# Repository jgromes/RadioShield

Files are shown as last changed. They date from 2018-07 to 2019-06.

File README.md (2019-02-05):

# Arduino Radio Shield

## "The Swiss Army Knife of Arduino Radio shields" - [Hackaday.com blog](https://hackaday.com/2018/07/28/why-have-only-one-radio-when-you-can-have-two/)

### Designed for use with [RadioLib](https://github.com/jgromes/RadioLib) - Universal wireless communication library for Arduino.

## Revision C
The latest hardware revision, compatible with both 5V and 3.3V Arduino boards. The entire project was also rebranded as Radio Shield!

Additional modules:
* **SIM800C** GSM module
* **CC1101** FSK module
* **nRF24L01** 2.4 GHz module

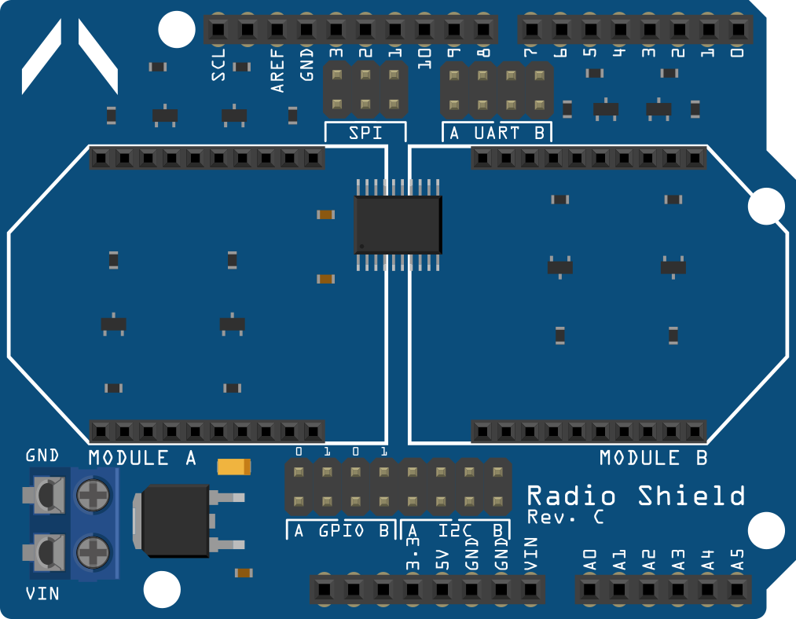
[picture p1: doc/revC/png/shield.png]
Radio Shield Rev.C


## Revision B
Added some improvements over rev. A, such as improved Arduino Mega support and interrupt selection pin header.

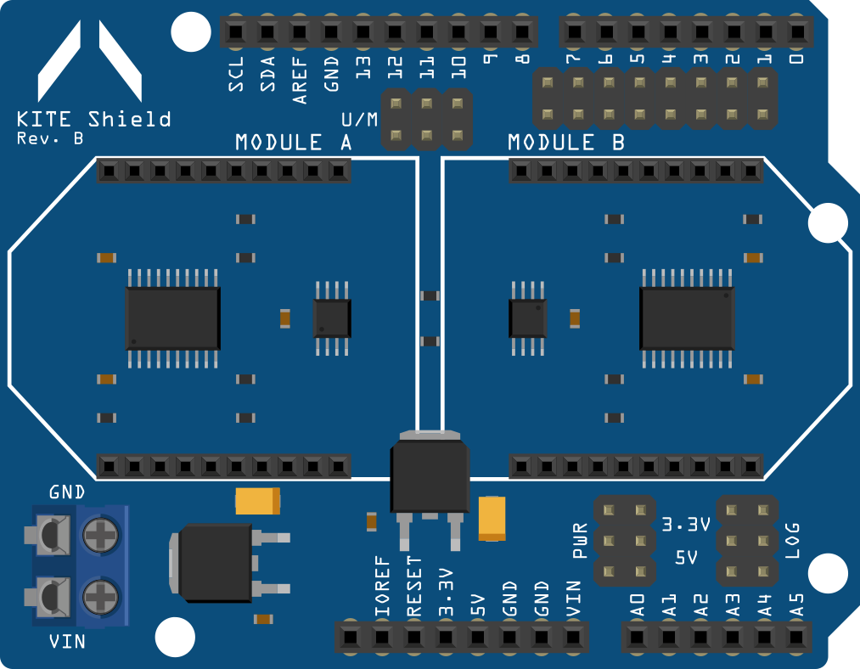
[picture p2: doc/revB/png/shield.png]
KITE Shield Rev.B


## Revision A
After a first few prototypes, rev. A is the first fully tested and working shield.  
Supported modules:
* **ESP8266** WiFi module
* **HC-05** Bluetooth module
* **RFM69** FSK/OOK radio module
* **SX127x** series LoRa modules - including SX1272, SX1276 and SX1278
* **XBee** modules (S2B)

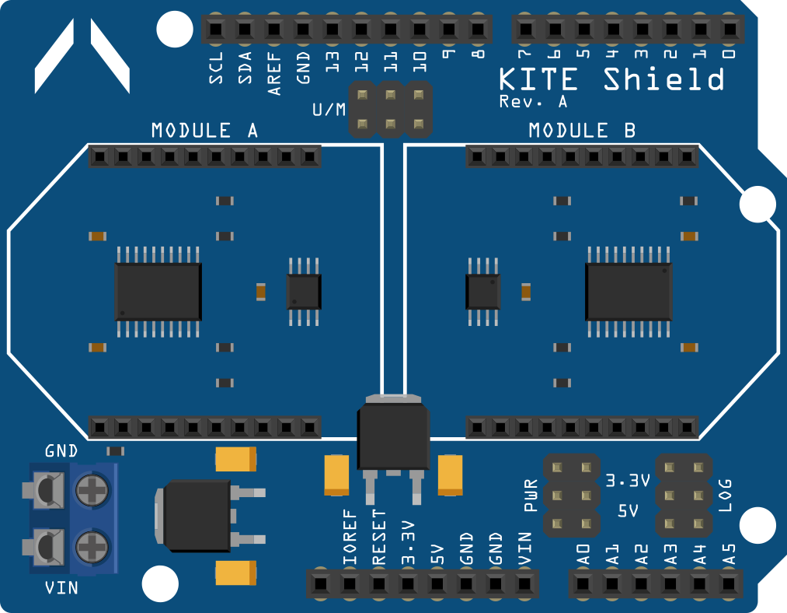
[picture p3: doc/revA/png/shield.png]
KITE Shield Rev.A


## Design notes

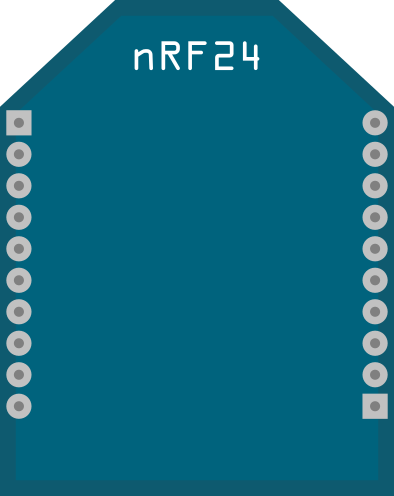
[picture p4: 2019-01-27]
doc/revC/png/module_nRF24.png

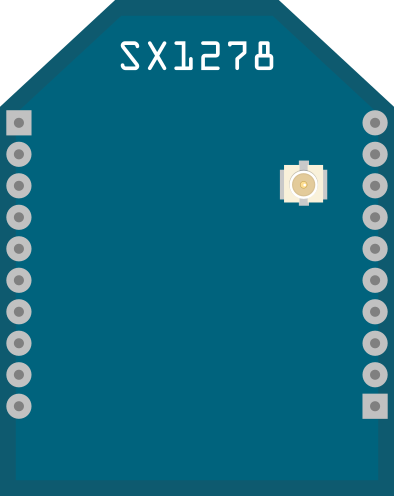
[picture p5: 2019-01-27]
doc/revC/png/module_SX1278_type1.png

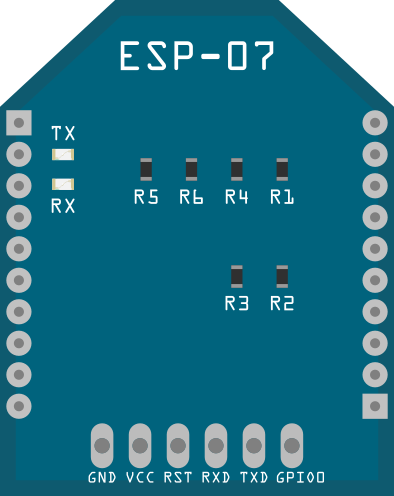
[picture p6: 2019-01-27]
doc/revC/png/module_ESP07.png

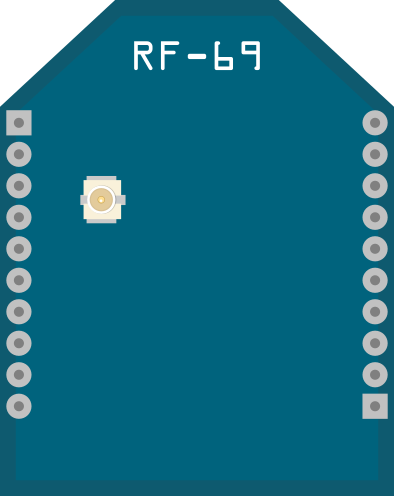
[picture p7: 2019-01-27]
doc/revC/png/module_RF69.png

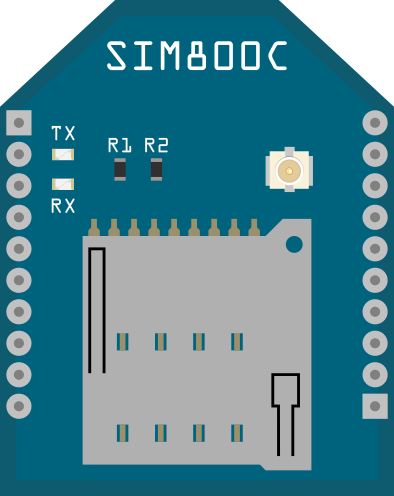
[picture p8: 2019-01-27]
doc/revC/png/module_SIM800C.png

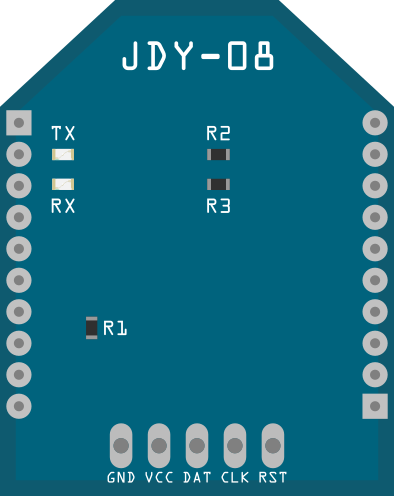
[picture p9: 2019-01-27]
doc/revC/png/module_JDY08.png

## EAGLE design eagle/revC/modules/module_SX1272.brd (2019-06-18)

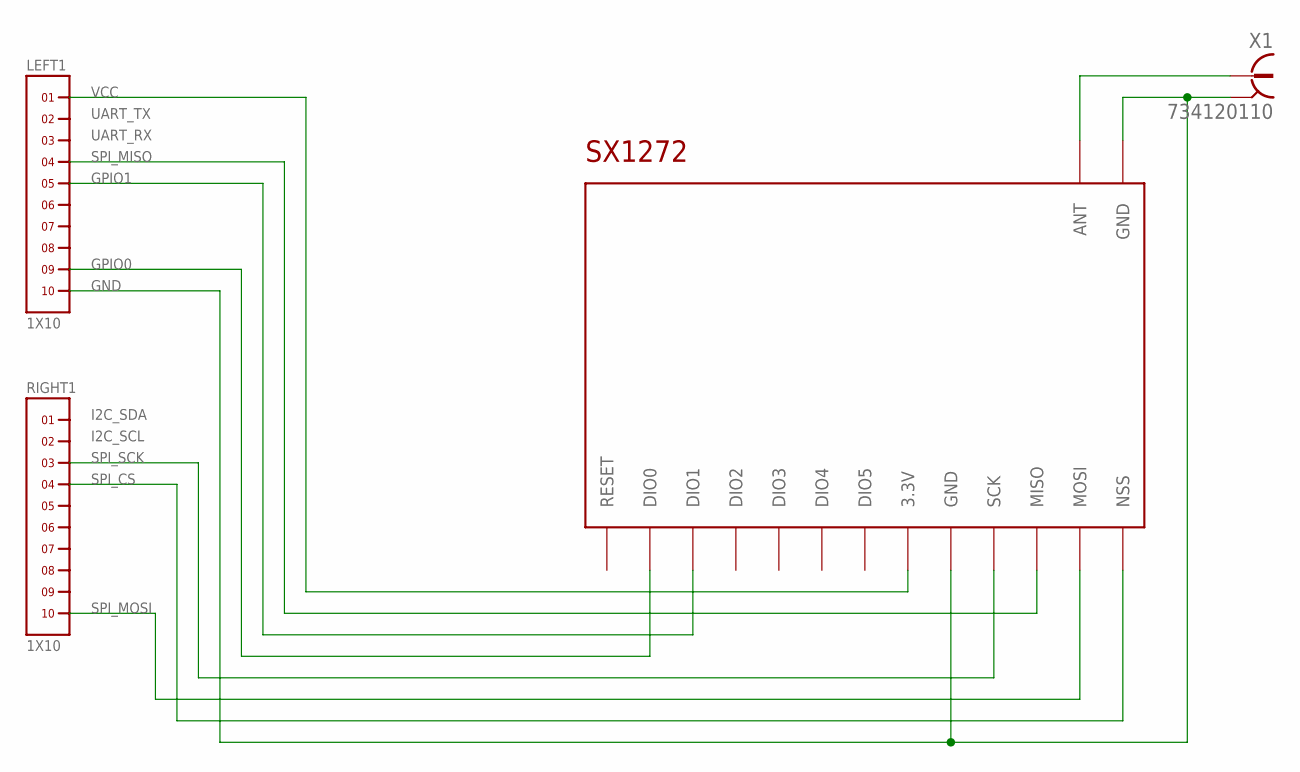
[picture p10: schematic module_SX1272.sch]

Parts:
LEFT1: 1X10
RIGHT1: 1X10
U$1: SX1272
X1: 734120110

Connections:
GND: LEFT1.10, U$1.GND@1 (GND), U$1.GND@2 (GND), X1.S@1 (2), X1.S@2 (2), X1.S@3 (2)
unnamed: U$1.ANT, X1.1
unnamed: LEFT1.9, U$1.DIO0
unnamed: RIGHT1.10, U$1.MOSI
unnamed: RIGHT1.4, U$1.NSS
unnamed: RIGHT1.3, U$1.SCK
unnamed: LEFT1.5, U$1.DIO1
unnamed: LEFT1.4, U$1.MISO
VCC: LEFT1.1, U$1.3.3V

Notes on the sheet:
VCC
UART_TX
UART_RX
SPI_MISO
GPIO1
GND
GPIO0
SPI_MOSI
I2C_SDA
I2C_SCL
SPI_SCK
SPI_CS

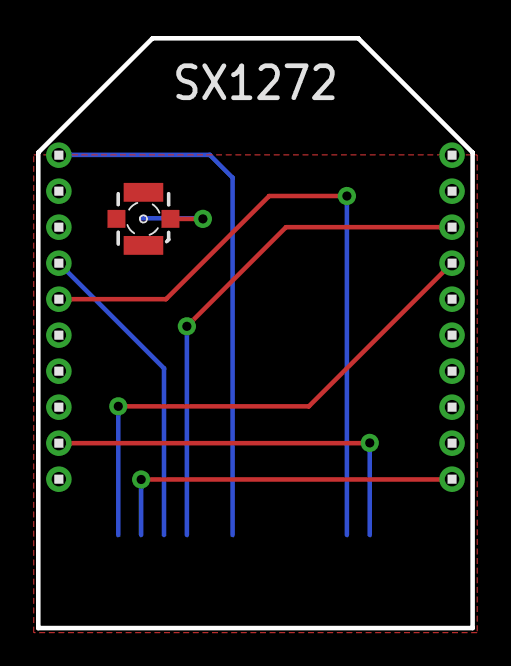
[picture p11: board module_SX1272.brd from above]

Board: 2 copper layers, 24.1 x 32.8 mm, 4 parts (1 on the bottom side), 9 nets.

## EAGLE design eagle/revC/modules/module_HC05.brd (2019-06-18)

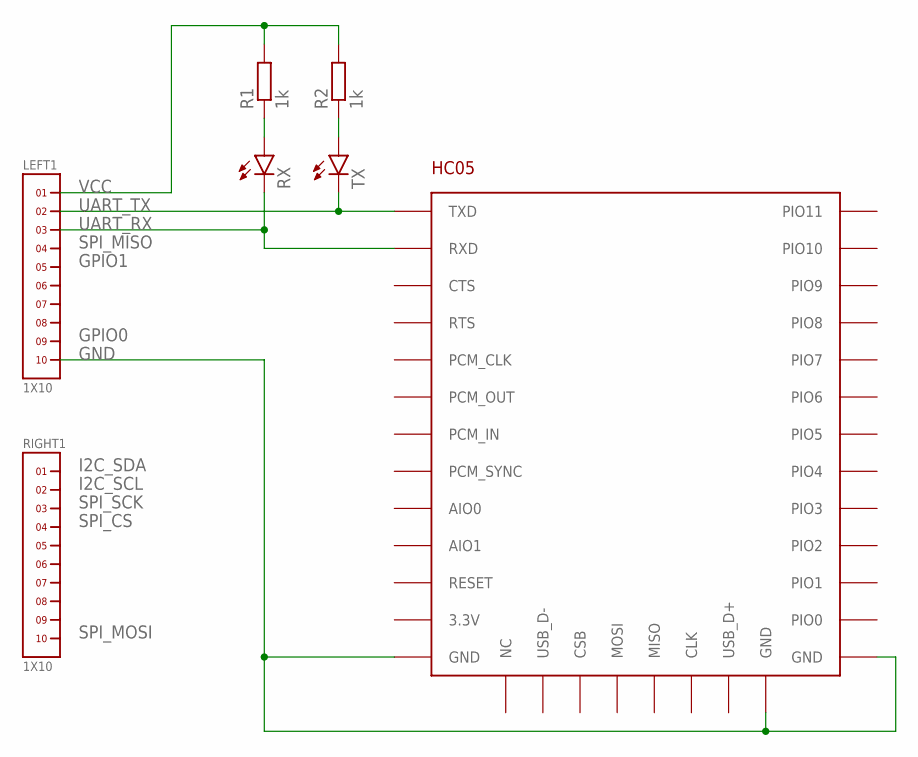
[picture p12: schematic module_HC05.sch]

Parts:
LEFT1: 1X10
R1, R2: 1k; R0603
RIGHT1: 1X10
RX: LEDCHIP-LED0603; CHIP-LED0603
TX: LEDCHIP-LED0603; CHIP-LED0603
U$1: HC05

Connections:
GND: LEFT1.10, U$1.GND@1 (GND), U$1.GND@2 (GND), U$1.GND@3 (GND)
unnamed: R2.1, TX.A
unnamed: R1.1, RX.A
unnamed: LEFT1.2, TX.C, U$1.TX (TXD)
unnamed: LEFT1.3, RX.C, U$1.RX (RXD)
VCC: LEFT1.1, R1.2, R2.2

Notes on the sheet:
VCC
I2C_SDA
I2C_SCL
SPI_SCK
SPI_CS
SPI_MOSI
UART_TX
UART_RX
SPI_MISO
GPIO1
GPIO0
GND

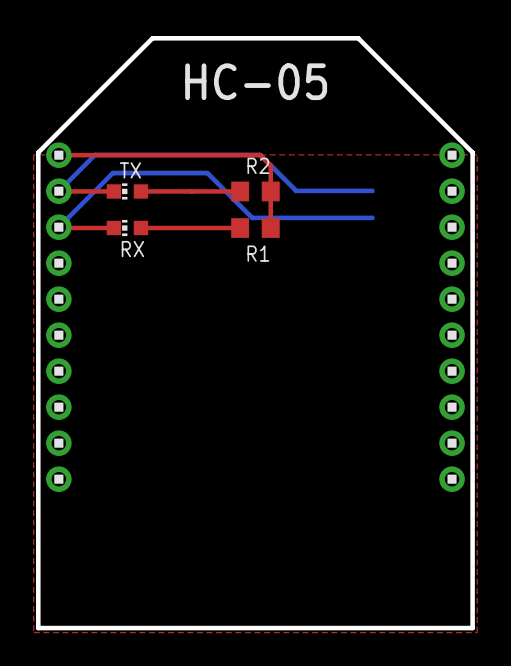
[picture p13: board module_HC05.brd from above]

Board: 2 copper layers, 24.1 x 32.8 mm, 7 parts (1 on the bottom side), 6 nets.

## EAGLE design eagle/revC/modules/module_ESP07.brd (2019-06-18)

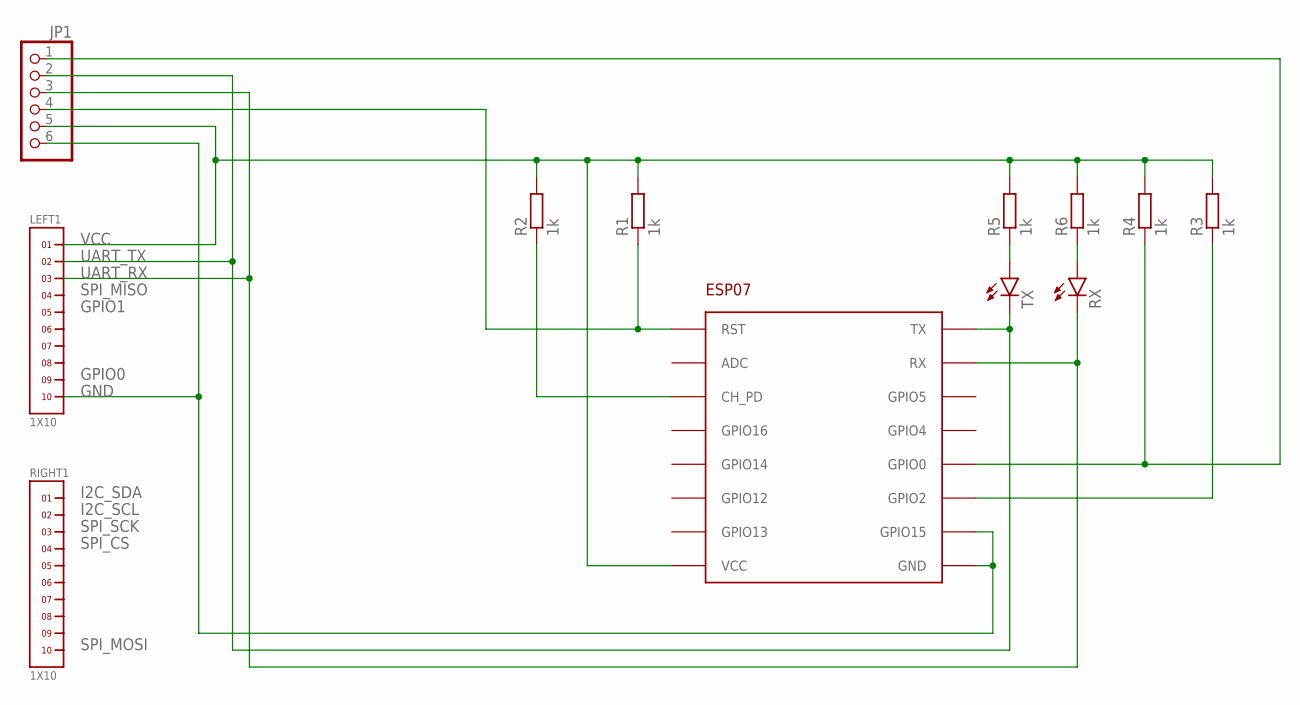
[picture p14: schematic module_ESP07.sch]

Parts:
JP1: PINHD-1X6; 1X06
LEFT1: 1X10
R1, R2, R3, R4, R5, R6: 1k; R0603
RIGHT1: 1X10
RX: LEDCHIPLED_0603; CHIPLED_0603
TX: LEDCHIPLED_0603; CHIPLED_0603
U$1: ESP-07; ESP07

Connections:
GND: JP1.6, LEFT1.10, U$1.GND, U$1.GPIO15
GPIO0: JP1.1, R4.1, U$1.GPIO0
unnamed: R6.1, RX.A
unnamed: R5.1, TX.A
unnamed: R2.1, U$1.CH_PD
unnamed: R3.1, U$1.GPIO2
RST: JP1.4, R1.1, U$1.RST
UART_RX: JP1.3, LEFT1.3, RX.C, U$1.RX
UART_TX: JP1.2, LEFT1.2, TX.C, U$1.TX
VCC: JP1.5, LEFT1.1, R1.2, R2.2, R3.2, R4.2, R5.2, R6.2, U$1.VCC

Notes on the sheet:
VCC
I2C_SDA
I2C_SCL
SPI_SCK
SPI_CS
SPI_MOSI
UART_TX
UART_RX
SPI_MISO
GPIO1
GPIO0
GND

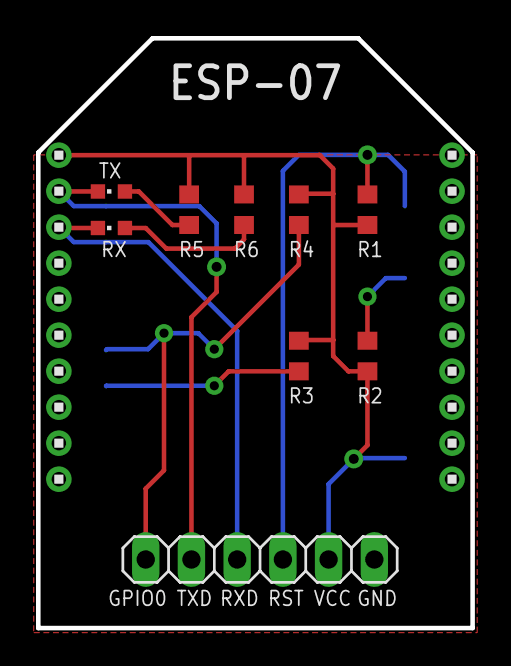
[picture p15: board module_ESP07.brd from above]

Board: 2 copper layers, 24.1 x 32.8 mm, 12 parts (1 on the bottom side), 10 nets.

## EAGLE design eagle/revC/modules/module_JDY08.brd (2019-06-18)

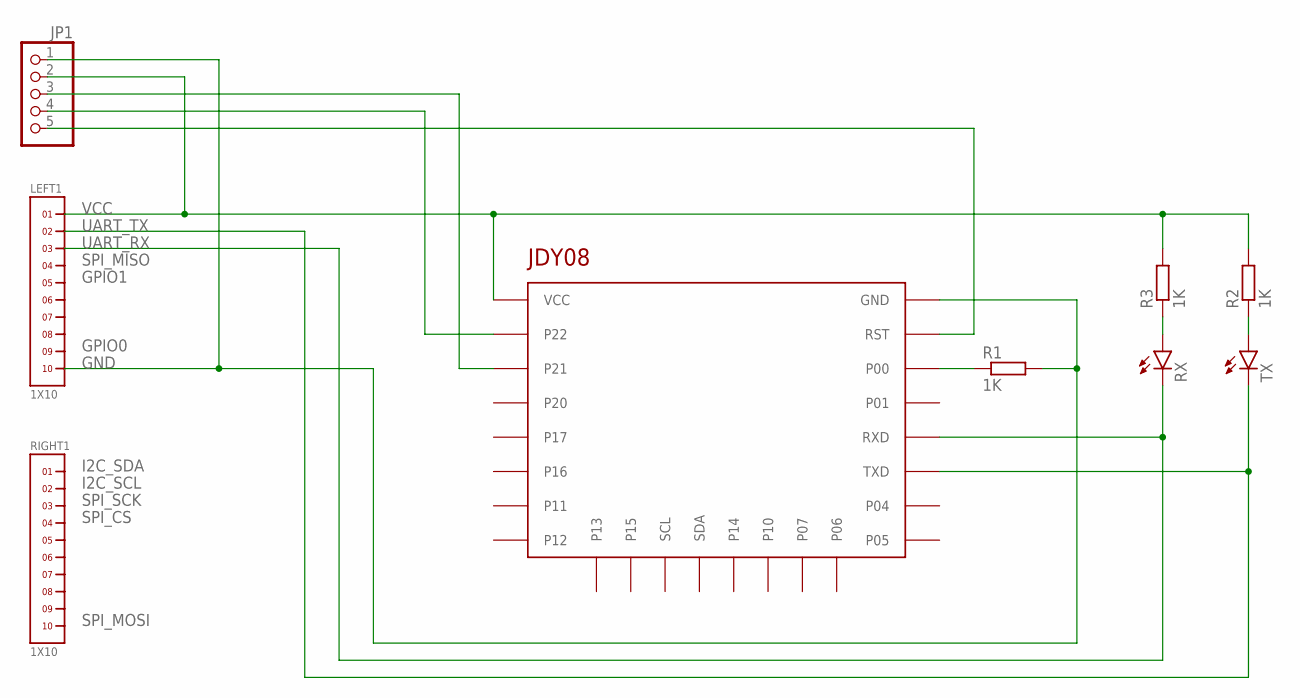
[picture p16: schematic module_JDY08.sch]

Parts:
JP1: PINHD-1X5; 1X05
LEFT1: 1X10
R1, R2, R3: 1K; R0603
RIGHT1: 1X10
RX: LEDCHIPLED_0603; CHIPLED_0603
TX: LEDCHIPLED_0603; CHIPLED_0603
U$1: JDY08

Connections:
GND: JP1.1, LEFT1.10, R1.2, U$1.GND
unnamed: JP1.5, U$1.RST
unnamed: JP1.3, U$1.P21
unnamed: JP1.4, U$1.P22
unnamed: LEFT1.3, RX.C, U$1.RXD
unnamed: R2.1, TX.A
unnamed: R3.1, RX.A
unnamed: R1.1, U$1.P00
unnamed: LEFT1.2, TX.C, U$1.TXD
VCC: JP1.2, LEFT1.1, R2.2, R3.2, U$1.VCC

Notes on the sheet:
VCC
I2C_SDA
I2C_SCL
SPI_SCK
SPI_CS
SPI_MOSI
UART_TX
UART_RX
SPI_MISO
GPIO1
GPIO0
GND

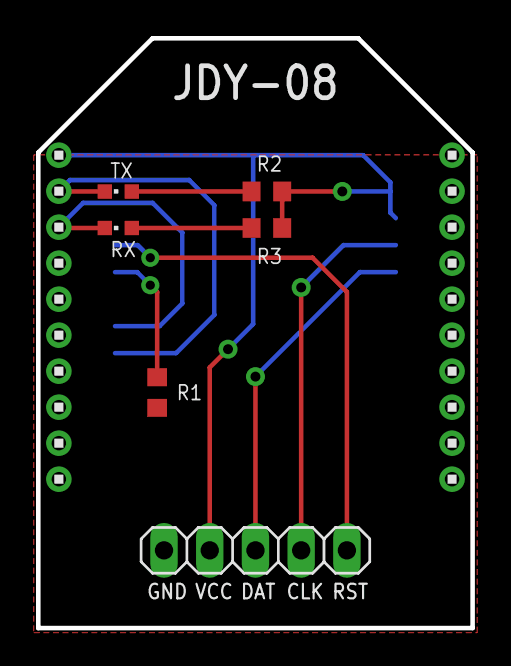
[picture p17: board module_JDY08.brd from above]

Board: 2 copper layers, 24.1 x 32.8 mm, 9 parts (1 on the bottom side), 10 nets.

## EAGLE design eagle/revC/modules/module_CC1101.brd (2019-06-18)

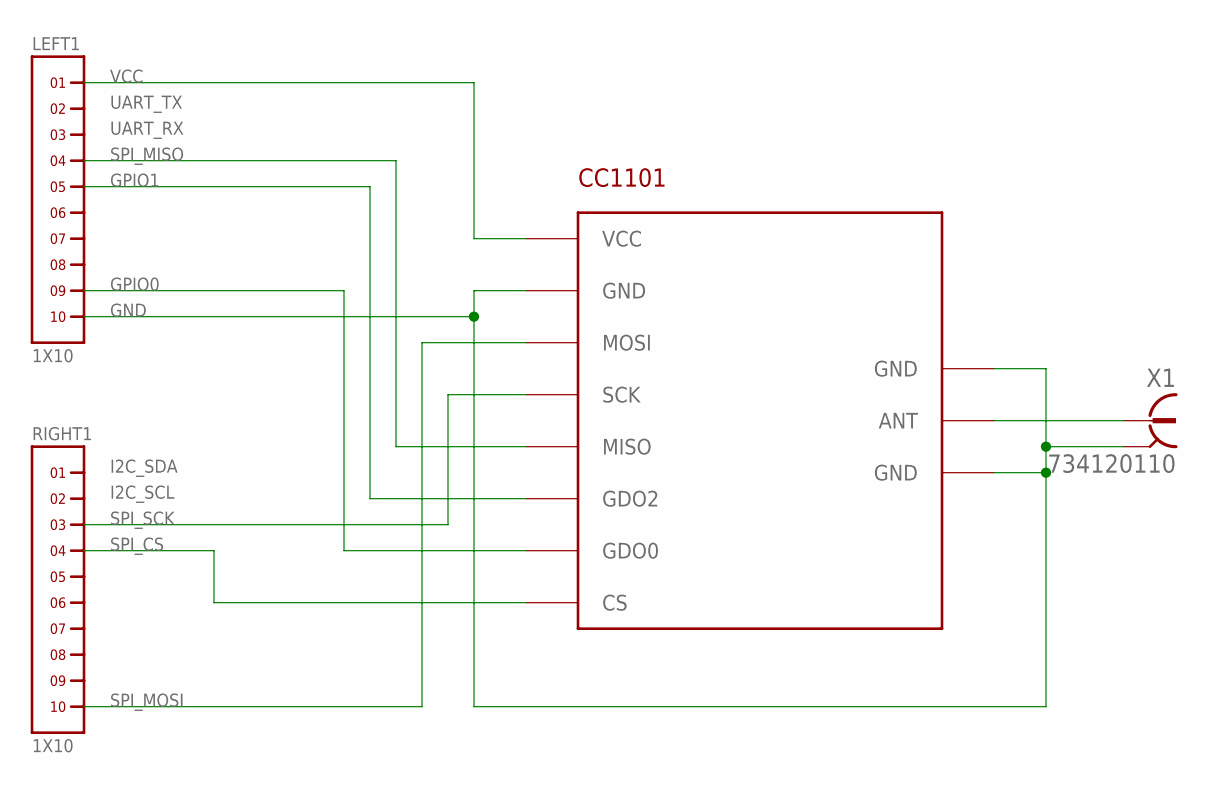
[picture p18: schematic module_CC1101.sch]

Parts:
CC1101: CC1101
LEFT1: 1X10
RIGHT1: 1X10
X1: 734120110

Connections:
GND: CC1101.GND@1 (GND), CC1101.GND@2 (GND), CC1101.GND@3 (GND), LEFT1.10, X1.S@1 (2), X1.S@2 (2), X1.S@3 (2)
INT0: CC1101.GDO0, LEFT1.9
INT1: CC1101.GDO2, LEFT1.5
unnamed: CC1101.ANT, X1.1
SPI_CS: CC1101.CS, RIGHT1.4
SPI_MISO: CC1101.MISO, LEFT1.4
SPI_MOSI: CC1101.MOSI, RIGHT1.10
SPI_SCK: CC1101.SCK, RIGHT1.3
VCC: CC1101.VCC, LEFT1.1

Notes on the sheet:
VCC
UART_TX
UART_RX
SPI_MISO
GPIO1
GND
GPIO0
SPI_MOSI
I2C_SDA
I2C_SCL
SPI_SCK
SPI_CS

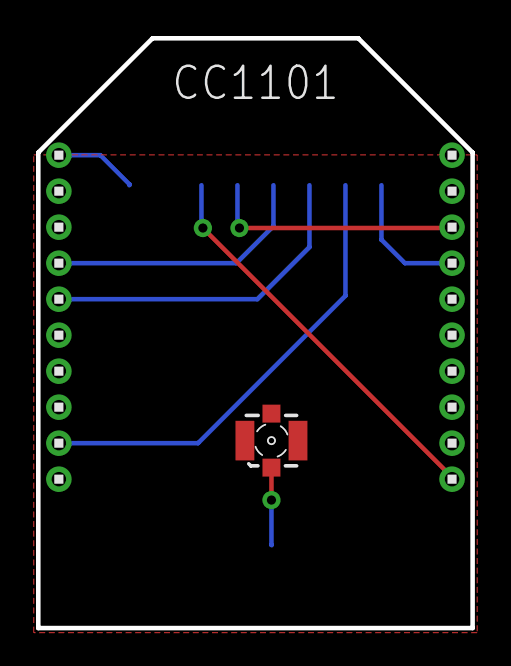
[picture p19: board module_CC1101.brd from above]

Board: 2 copper layers, 24.1 x 32.8 mm, 4 parts (1 on the bottom side), 9 nets.

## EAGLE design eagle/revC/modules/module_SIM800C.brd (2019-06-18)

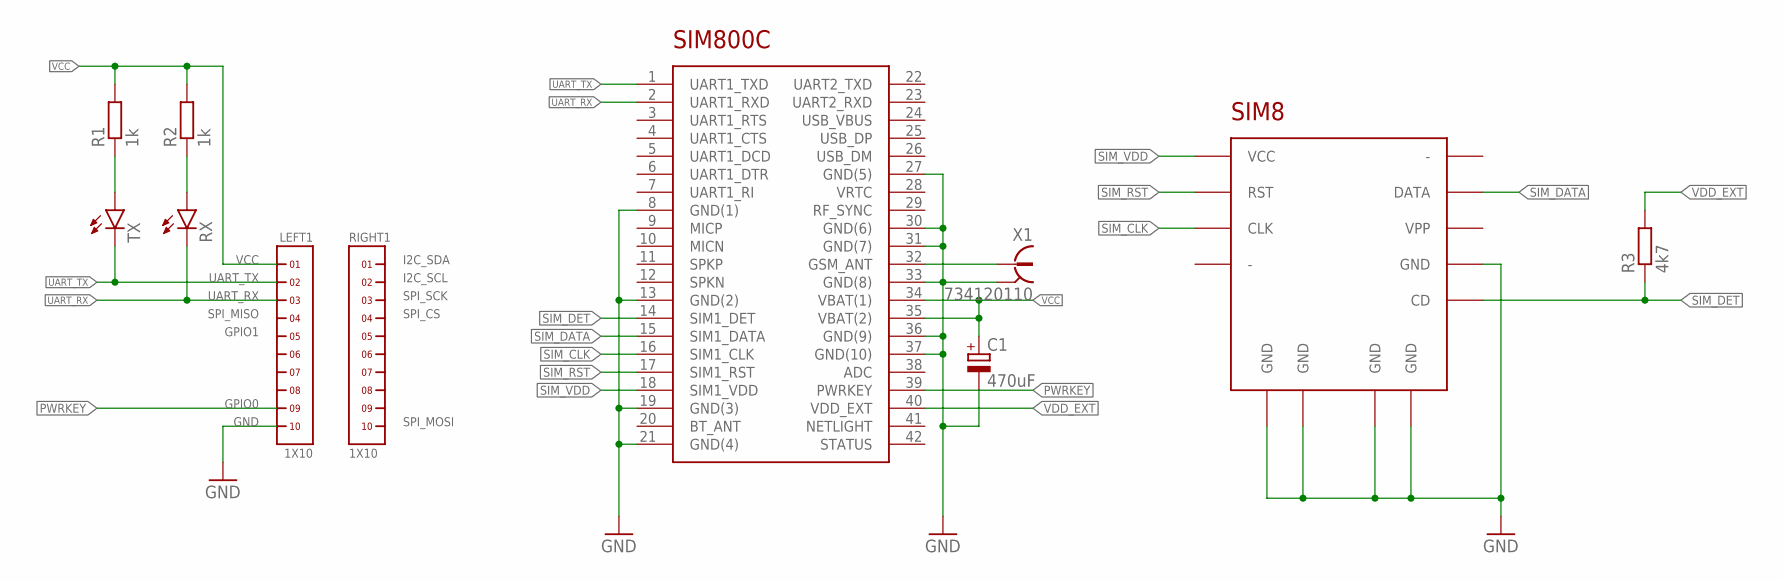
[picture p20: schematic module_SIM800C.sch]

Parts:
C1: 470uF; SMC_D
IC1: SIM800C
LEFT1: 1X10
R1, R2: 1k; R0603
R3: 4k7; R0603
RIGHT1: 1X10
RX: LEDCHIPLED_0603; CHIPLED_0603
TX: LEDCHIPLED_0603; CHIPLED_0603
U$2: 115Q-BCA0
X1: 734120110

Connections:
GND: C1.-, IC1.8 (GND(1)), IC1.13 (GND(2)), IC1.19 (GND(3)), IC1.21 (GND(4)), IC1.27 (GND(5)), IC1.30 (GND(6)), IC1.31 (GND(7)), IC1.33 (GND(8)), IC1.36 (GND(9)), IC1.37 (GND(10)), LEFT1.10, U$2.P$5 (GND), U$2.P$10 (GND), U$2.P$11 (GND), U$2.P$12 (GND), U$2.P$13 (GND), X1.S@1 (2), X1.S@2 (2), X1.S@3 (2)
unnamed: IC1.32 (GSM_ANT), X1.1
unnamed: R1.1, TX.A
unnamed: R2.1, RX.A
PWRKEY: IC1.39 (PWRKEY), LEFT1.9
SIM_CLK: IC1.16 (SIM1_CLK), U$2.P$3 (CLK)
SIM_DATA: IC1.15 (SIM1_DATA), U$2.P$7 (DATA)
SIM_DET: IC1.14 (SIM1_DET), R3.1, U$2.P$9 (CD)
SIM_RST: IC1.17 (SIM1_RST), U$2.P$2 (RST)
SIM_VDD: IC1.18 (SIM1_VDD), U$2.P$1 (VCC)
UART_RX: IC1.2 (UART1_RXD), LEFT1.3, RX.C
UART_TX: IC1.1 (UART1_TXD), LEFT1.2, TX.C
VCC: C1.+, IC1.34 (VBAT(1)), IC1.35 (VBAT(2)), LEFT1.1, R1.2, R2.2
VDD_EXT: IC1.40 (VDD_EXT), R3.2

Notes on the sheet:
VCC
UART_TX
UART_RX
SPI_MISO
GPIO1
GND
GPIO0
SPI_MOSI
I2C_SDA
I2C_SCL
SPI_SCK
SPI_CS

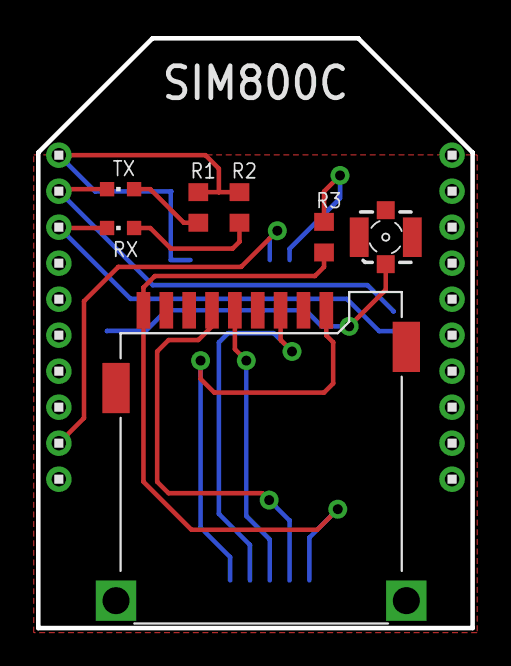
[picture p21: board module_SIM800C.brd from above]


Board: 2 copper layers, 24.1 x 32.8 mm, 11 parts (2 on the bottom side), 14 nets.

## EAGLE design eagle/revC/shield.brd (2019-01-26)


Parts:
AD: PINHD-1X6; 1X06
C1, C3, C4: 0.1 uF; C0603
C2: 2.2 uF; SMC_A
CON_A_LEFT: 1X10
CON_A_RIGHT: 1X10
CON_B_LEFT: 1X10
CON_B_RIGHT: 1X10
GPIO: PINHD-2X4; 2X04
I2C: PINHD-2X4; 2X04
IOH: PINHD-1X10; 1X10
IOL: PINHD-1X8; 1X08
POWER: PINHD-1X8; 1X08
POWER_IN: W237-102
Q1, Q2, Q3, Q4, Q5, Q6, Q7, Q8: BSS138; SOT23
R1, R2, R3, R4, R5, R6, R7, R8, R9, R10, R11, R12, R13, R14, R15, R16: 10k; R0603
SPI: PINHD-2X3; 2X03
U1: MAX3001; TSSOP20
U2: KF33BDT-TR; TO228P972X240-3N
UART: PINHD-2X4; 2X04

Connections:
+3V3: C2.+, CON_A_LEFT.1, CON_B_LEFT.1, U2.3 (OUTPUT)
+3V3_REF: C3.1, POWER.4, Q1.1 (G), Q2.1 (G), Q3.1 (G), Q4.1 (G), Q5.1 (G), Q6.1 (G), Q7.1 (G), Q8.1 (G), R1.2, R3.2, R5.2, R7.2, R9.2, R11.2, R13.2, R15.2, U1.2 (VL), U1.10 (EN)
+5V0_REF: POWER.5
ARD_CS_A: IOH.8, U1.16 (VCC4)
ARD_CS_B: IOL.3, U1.15 (VCC5)
ARD_GPIO0: IOL.6, Q2.3 (D), R4.1
ARD_GPIO1: IOL.5, Q1.3 (D), R2.1
ARD_MISO: SPI.3, U1.18 (VCC2)
ARD_MOSI: SPI.5, U1.17 (VCC3)
ARD_RX_A: Q5.3 (D), R10.1, UART.1
ARD_RX_B: Q7.3 (D), R14.1, UART.5
ARD_SCK: SPI.1, U1.20 (VCC1)
ARD_SCL: IOH.1, Q4.3 (D), R8.1
ARD_SDA: IOH.2, Q3.3 (D), R6.1
ARD_TX_A: Q6.3 (D), R12.1, UART.3
ARD_TX_B: Q8.3 (D), R16.1, UART.7
CON_A_CS: CON_A_RIGHT.4, U1.5 (VL4)
CON_A_GPIO0: CON_A_LEFT.9, GPIO.4
CON_A_GPIO1: CON_A_LEFT.5, GPIO.2
CON_A_RX: CON_A_LEFT.2, Q5.2 (S), R9.1
CON_A_SCL: CON_A_RIGHT.2, I2C.4
CON_A_SDA: CON_A_RIGHT.1, I2C.2
CON_A_TX: CON_A_LEFT.3, Q6.2 (S), R11.1
CON_B_CS: CON_B_RIGHT.4, U1.6 (VL5)
CON_B_GPIO0: CON_B_LEFT.9, GPIO.8
CON_B_GPIO1: CON_B_LEFT.5, GPIO.6
CON_B_RX: CON_B_LEFT.2, Q7.2 (S), R13.1
CON_B_SCL: CON_B_RIGHT.2, I2C.8
CON_B_SDA: CON_B_RIGHT.1, I2C.6
CON_B_TX: CON_B_LEFT.3, Q8.2 (S), R15.1
CON_MISO: CON_A_LEFT.4, CON_B_LEFT.4, U1.3 (VL2)
CON_MOSI: CON_A_RIGHT.10, CON_B_RIGHT.10, U1.4 (VL3)
CON_SCK: CON_A_RIGHT.3, CON_B_RIGHT.3, U1.1 (VL1)
GND: C1.2, C2.-, C3.2, C4.2, CON_A_LEFT.10, CON_B_LEFT.10, IOH.4, POWER.6, POWER.7, POWER_IN.1, U1.11 (GND), U2.4 (GND_TAB)
GPIO0_S: GPIO.3, GPIO.7, Q2.2 (S), R3.1
GPIO1_S: GPIO.1, GPIO.5, Q1.2 (S), R1.1
IOREF: C4.1, POWER.2, R2.2, R4.2, R6.2, R8.2, R10.2, R12.2, R14.2, R16.2, U1.19 (VCC)
RESET: POWER.3
SCL_S: I2C.3, I2C.7, Q4.2 (S), R7.1
SDA_S: I2C.1, I2C.5, Q3.2 (S), R5.1
UNO_MISO: IOH.6, SPI.4
UNO_MOSI: IOH.7, SPI.6
UNO_RX_A: IOH.9, UART.2
UNO_RX_B: IOL.1, UART.6
UNO_SCK: IOH.5, SPI.2
UNO_TX_A: IOH.10, UART.4
UNO_TX_B: IOL.2, UART.8
VIN: C1.1, POWER.8, POWER_IN.2, U2.1 (INPUT)

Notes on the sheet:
Jan Gromes
AREF
SDA
SCL
VIN
GND
3.3V
RESET
IOREF
MODULE B LEVEL TRANSLATORS
MODULE A LEVEL TRANSLATORS
MODULE A
MODULE B
POWER
ARDUINO HEADERS
Arduino Radio shield
Designed in Czech Republic by Atlas Inc.
CONFIGURATION HEADERS
COMMON LEVEL TRANSLATORS
Notes: 1. UART signal names respect data flow to/from Arduino.


Board: 2 copper layers, 68.6 x 53.3 mm, 43 parts (0 on the bottom side), 46 nets.

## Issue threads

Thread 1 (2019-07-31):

What's about ESP32 support ?

Vorms, 2019-07-31:
All is in the title...

Best regards

jgromes, 2019-07-31:
RadioShield is compatible with any board that's compatible with Arduino Uno R3.

Did you mean to post this in https://github.com/jgromes/RadioLib?

Vorms, 2019-07-31:
yes of corse for the library
Thanks
I am intersted about a RF69 -> MQTT !

Best regards and thanks for your works

jgromes, 2019-07-31:
Could you post this to the library repository? Thanks

Closed 2019-07-31.

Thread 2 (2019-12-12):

Library Errors Latest Version w/ Artemis RedBoard

cvoalex, 2019-12-12:
Latest version trying to compile the Transmit and Receive demos for SX126x with an Artemis Redboard.   Seems new function setpin that was not in previous versions doesnt have correct parameters when compiled for Artemis.

"C:\\Users\\Alexander\\AppData\\Local\\Arduino15\\packages\\SparkFun\\tools\\arm-none-eabi-gcc\\8-2018-q4-major/bin/arm-none-eabi-g++" -DPART_apollo3 -DAM_PACKAGE_BGA -DAM_PART_APOLLO3 -c -g -MMD -mcpu=cortex-m4 -mthumb -mfloat-abi=hard -fdata-sections -Os -ffunction-sections -std=gnu++11 -fno-threadsafe-statics -nostdlib --param max-inline-insns-single=500 -fno-rtti -fno-exceptions -DF_CPU=48000000L -DARDUINO=10810 -DARDUINO_AM_AP3_SFE_BB_ARTEMIS -DARDUINO_ARCH_APOLLO3 "-IC:\\Users\\Alexander\\AppData\\Local\\Arduino15\\packages\\SparkFun\\hardware\\apollo3\\1.0.17\\variants\\SparkFun_RedBoard_Artemis/config" "-IC:\\Users\\Alexander\\AppData\\Local\\Arduino15\\packages\\SparkFun\\hardware\\apollo3\\1.0.17\\variants\\SparkFun_RedBoard_Artemis/bsp" "-IC:\\Users\\Alexander\\AppData\\Local\\Arduino15\\packages\\SparkFun\\hardware\\apollo3\\1.0.17/cores/arduino/ard_sup" "-IC:\\Users\\Alexander\\AppData\\Local\\Arduino15\\packages\\SparkFun\\hardware\\apollo3\\1.0.17/cores/arduino/ard_sup/ard_supers" "-IC:\\Users\\Alexander\\AppData\\Local\\Arduino15\\packages\\SparkFun\\hardware\\apollo3\\1.0.17\\cores\\arduino" "-IC:\\Users\\Alexander\\AppData\\Local\\Arduino15\\packages\\SparkFun\\hardware\\apollo3\\1.0.17\\variants\\SparkFun_RedBoard_Artemis" "-IC:\\Users\\Alexander\\Documents\\Arduino\\libraries\\RadioLib\\src" "-IC:\\Users\\Alexander\\AppData\\Local\\Arduino15\\packages\\SparkFun\\hardware\\apollo3\\1.0.17\\libraries\\SPI\\src" "-IC:\\Users\\Alexander\\AppData\\Local\\Arduino15\\packages\\SparkFun\\hardware\\apollo3\\1.0.17\\libraries\\SoftwareSerial\\src" "-IC:\\Users\\Alexander\\AppData\\Local\\Arduino15\\packages\\SparkFun\\hardware\\apollo3\\1.0.17/cores/arduino/am_sdk_ap3/mcu/apollo3" "-IC:\\Users\\Alexander\\AppData\\Local\\Arduino15\\packages\\SparkFun\\hardware\\apollo3\\1.0.17/cores/arduino/am_sdk_ap3/mcu/apollo3/hal" "-IC:\\Users\\Alexander\\AppData\\Local\\Arduino15\\packages\\SparkFun\\hardware\\apollo3\\1.0.17/cores/arduino/am_sdk_ap3/mcu/apollo3/regs" "-IC:\\Users\\Alexander\\AppData\\Local\\Arduino15\\packages\\SparkFun\\hardware\\apollo3\\1.0.17/cores/arduino/am_sdk_ap3/utils" "-IC:\\Users\\Alexander\\AppData\\Local\\Arduino15\\packages\\SparkFun\\hardware\\apollo3\\1.0.17/cores/arduino/am_sdk_ap3/devices" "-IC:\\Users\\Alexander\\AppData\\Local\\Arduino15\\packages\\SparkFun\\hardware\\apollo3\\1.0.17/cores/arduino/am_sdk_ap3/CMSIS/AmbiqMicro/Include" "-IC:\\Users\\Alexander\\AppData\\Local\\Arduino15\\packages\\SparkFun\\hardware\\apollo3\\1.0.17/cores/arduino/am_sdk_ap3/CMSIS/ARM/Include" "C:\\Users\\Alexander\\Documents\\Arduino\\libraries\\RadioLib\\src\\ISerial.cpp" -o "C:\\Users\\ALEXAN~1\\AppData\\Local\\Temp\\arduino_build_628036\\libraries\\RadioLib\\ISerial.cpp.o"
C:\Users\Alexander\Documents\Arduino\libraries\RadioLib\src\Module.cpp: In member function 'void Module::init(uint8_t, uint8_t)':
C:\Users\Alexander\Documents\Arduino\libraries\RadioLib\src\Module.cpp:59:25: error: no matching function for call to 'Module::setPin(int&, const am_hal_gpio_pincfg_t&)'
       setPin(_cs, OUTPUT);
                         ^
In file included from C:\Users\Alexander\Documents\Arduino\libraries\RadioLib\src\Module.cpp:1:
C:\Users\Alexander\Documents\Arduino\libraries\RadioLib\src\Module.h:327:10: note: candidate: 'void Module::setPin(int16_t, uint8_t)'
     void setPin(int16_t pin, uint8_t mode);
          ^~~~~~
C:\Users\Alexander\Documents\Arduino\libraries\RadioLib\src\Module.h:327:10: note:   no known conversion for argument 2 from 'const am_hal_gpio_pincfg_t' to 'uint8_t' {aka 'unsigned char'}
C:\Users\Alexander\Documents\Arduino\libraries\RadioLib\src\Module.cpp:79:26: error: no matching function for call to 'Module::setPin(int&, const am_hal_gpio_pincfg_t&)'
       setPin(_int0, INPUT);
                          ^
In file included from C:\Users\Alexander\Documents\Arduino\libraries\RadioLib\src\Module.cpp:1:
C:\Users\Alexander\Documents\Arduino\libraries\RadioLib\src\Module.h:327:10: note: candidate: 'void Module::setPin(int16_t, uint8_t)'
     void setPin(int16_t pin, uint8_t mode);
          ^~~~~~
C:\Users\Alexander\Documents\Arduino\libraries\RadioLib\src\Module.h:327:10: note:   no known conversion for argument 2 from 'const am_hal_gpio_pincfg_t' to 'uint8_t' {aka 'unsigned char'}
C:\Users\Alexander\Documents\Arduino\libraries\RadioLib\src\Module.cpp:82:26: error: no matching function for call to 'Module::setPin(int&, const am_hal_gpio_pincfg_t&)'
       setPin(_int1, INPUT);
                          ^
In file included from C:\Users\Alexander\Documents\Arduino\libraries\RadioLib\src\Module.cpp:1:
C:\Users\Alexander\Documents\Arduino\libraries\RadioLib\src\Module.h:327:10: note: candidate: 'void Module::setPin(int16_t, uint8_t)'
     void setPin(int16_t pin, uint8_t mode);
          ^~~~~~
C:\Users\Alexander\Documents\Arduino\libraries\RadioLib\src\Module.h:327:10: note:   no known conversion for argument 2 from 'const am_hal_gpio_pincfg_t' to 'uint8_t' {aka 'unsigned char'}
C:\Users\Alexander\Documents\Arduino\libraries\RadioLib\src\Module.cpp:85:26: error: no matching function for call to 'Module::setPin(int&, const am_hal_gpio_pincfg_t&)'
       setPin(_int0, INPUT);
                          ^
In file included from C:\Users\Alexander\Documents\Arduino\libraries\RadioLib\src\Module.cpp:1:
C:\Users\Alexander\Documents\Arduino\libraries\RadioLib\src\Module.h:327:10: note: candidate: 'void Module::setPin(int16_t, uint8_t)'
     void setPin(int16_t pin, uint8_t mode);
          ^~~~~~
C:\Users\Alexander\Documents\Arduino\libraries\RadioLib\src\Module.h:327:10: note:   no known conversion for argument 2 from 'const am_hal_gpio_pincfg_t' to 'uint8_t' {aka 'unsigned char'}
C:\Users\Alexander\Documents\Arduino\libraries\RadioLib\src\Module.cpp:86:26: error: no matching function for call to 'Module::setPin(int&, const am_hal_gpio_pincfg_t&)'
       setPin(_int1, INPUT);
                          ^
In file included from C:\Users\Alexander\Documents\Arduino\libraries\RadioLib\src\Module.cpp:1:
C:\Users\Alexander\Documents\Arduino\libraries\RadioLib\src\Module.h:327:10: note: candidate: 'void Module::setPin(int16_t, uint8_t)'
     void setPin(int16_t pin, uint8_t mode);
          ^~~~~~
C:\Users\Alexander\Documents\Arduino\libraries\RadioLib\src\Module.h:327:10: note:   no known conversion for argument 2 from 'const am_hal_gpio_pincfg_t' to 'uint8_t' {aka 'unsigned char'}
C:\Users\Alexander\Documents\Arduino\libraries\RadioLib\src\Module.cpp: In member function 'void Module::setPin(int16_t, uint8_t)':
C:\Users\Alexander\Documents\Arduino\libraries\RadioLib\src\Module.cpp:258:22: error: no matching function for call to 'pinMode(int16_t&, uint8_t&)'
     pinMode(pin, mode);
                      ^
In file included from C:\Users\Alexander\AppData\Local\Arduino15\packages\SparkFun\hardware\apollo3\1.0.17/cores/arduino/ard_sup/Arduino.h:77,
                 from C:\Users\Alexander\Documents\Arduino\libraries\RadioLib\src\TypeDef.h:4,
                 from C:\Users\Alexander\Documents\Arduino\libraries\RadioLib\src\Module.h:4,
                 from C:\Users\Alexander\Documents\Arduino\libraries\RadioLib\src\Module.cpp:1:
C:\Users\Alexander\AppData\Local\Arduino15\packages\SparkFun\hardware\apollo3\1.0.17/cores/arduino/ard_sup/ap3_gpio.h:62:6: note: candidate: 'void pinMode(uint8_t, am_hal_gpio_pincfg_t)'
 void pinMode(uint8_t pin, am_hal_gpio_pincfg_t mode);
      ^~~~~~~
C:\Users\Alexander\AppData\Local\Arduino15\packages\SparkFun\hardware\apollo3\1.0.17/cores/arduino/ard_sup/ap3_gpio.h:62:6: note:   no known conversion for argument 2 from 'uint8_t' {aka 'unsigned char'} to 'am_hal_gpio_pincfg_t'
C:\Users\Alexander\AppData\Local\Arduino15\packages\SparkFun\hardware\apollo3\1.0.17/cores/arduino/ard_sup/ap3_gpio.h:63:6: note: candidate: 'void pinMode(uint8_t, am_hal_gpio_pincfg_t, ap3_err_t*)'
 void pinMode(uint8_t pin, am_hal_gpio_pincfg_t mode, ap3_err_t *retval);
      ^~~~~~~
C:\Users\Alexander\AppData\Local\Arduino15\packages\SparkFun\hardware\apollo3\1.0.17/cores/arduino/ard_sup/ap3_gpio.h:63:6: note:   candidate expects 3 arguments, 2 provided
C:\Users\Alexander\Documents\Arduino\libraries\RadioLib\src\ISerial.cpp: In member function 'bool ISerial::listen()':
C:\Users\Alexander\Documents\Arduino\libraries\RadioLib\src\ISerial.cpp:15:38: error: void value not ignored as it ought to be
   return(_mod->ModuleSerial->listen());
                                      ^
C:\Users\Alexander\Documents\Arduino\libraries\RadioLib\src\ISerial.cpp: In member function 'bool ISerial::stopListening()':
C:\Users\Alexander\Documents\Arduino\libraries\RadioLib\src\ISerial.cpp:35:45: error: void value not ignored as it ought to be
   return(_mod->ModuleSerial->stopListening());

jgromes, 2019-12-12:
You probably menat to post this in the [RadioLib](https://github.com/jgromes/RadioLib) repository.

Apollo3 is not a platform supported by RadioLib, so if it ever worked at all, it was by random chance rather than by design. I'm also not sure supporting these unicorn MCUs is worthwhile - the Travis CI script already takes half an hour to build all the examples, I don't want to add to it. Though if the build process for Apollo is fast enough, it could be added.

cvoalex, 2019-12-12:
Hi Jan
Is it possible to pay you for some consulting work to get this MCU supported ?  It is from SparkFun and it is quite powerful and getting some wide adoption

Let me know
Thx
Alex

Sent from my iPhone

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

Closed 2019-12-12.

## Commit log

2018-07-14 Added Eagle files for revision A
    [module_ESP07.brd, module_ESP07.sch, module_HC05.brd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]
2018-07-17 Added eagle files for shield rev.B
    [shield.brd, shield.sch]
2018-07-17 Added eagle files for JDY-08 Bluetooth breakout board
    [module_JDY08.brd, module_JDY08.sch]
2018-07-17 Added eagle files for SX1272 breakout board
    [module_SX1272.brd, module_SX1272.sch]
2018-07-17 Updated SX1272 layout
    [module_SX1272.brd]
2018-07-17 Added eagle files for HC-05
    [module_HC05.brd, module_HC05.sch]
2018-07-19 Added eagle files for SX1278
    [module_SX1278_type1.brd, module_SX1278_type1.sch, module_SX1278_type2.brd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]
2018-07-20 Added eagle files for ESP-07
    [module_ESP07.brd, module_ESP07.sch]
2018-07-20 Added eagle files for RF69
    [module_RF69.brd, module_RF69.sch]
2018-07-29 ESP8266 - Added indication LEDs
    [module_ESP07.brd, module_ESP07.sch]
2019-01-08 Added eagle files for SIM800C
    [module_SIM800C.brd, module_SIM800C.sch]
2019-01-08 [SIM800C] Updated layout
    [module_SIM800C.brd]
2019-01-26 Added rev. C eagle files
    [module_CC1101.brd, module_CC1101.sch, module_ESP07.brd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]
2019-02-10 [SIM800C] Added PWRKEY connection
    [module_SIM800C.brd, module_SIM800C.sch]
2019-02-10 [SIM800C] Fixed incorrect SIM slot wiring
    [module_SIM800C.brd, module_SIM800C.sch]
2019-02-10 [SIM800] Added SIM detection pullup
    [module_SIM800C.brd, module_SIM800C.sch]
2019-05-27 Replaced modules with library parts
    [module_CC1101.brd, module_CC1101.sch, module_ESP07.brd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]
2019-05-27 Added SX1262 breakout
    [module_SX1262.brd, module_SX1262.sch]
2019-06-18 Fixed module name layers
    [module_CC1101.brd, module_CC1101.sch, module_ESP07.brd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]
